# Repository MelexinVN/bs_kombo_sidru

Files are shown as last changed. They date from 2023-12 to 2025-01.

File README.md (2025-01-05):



# СИДРУ
## СветоИзлучающее Декоративное Радиоуправляемое Устройство

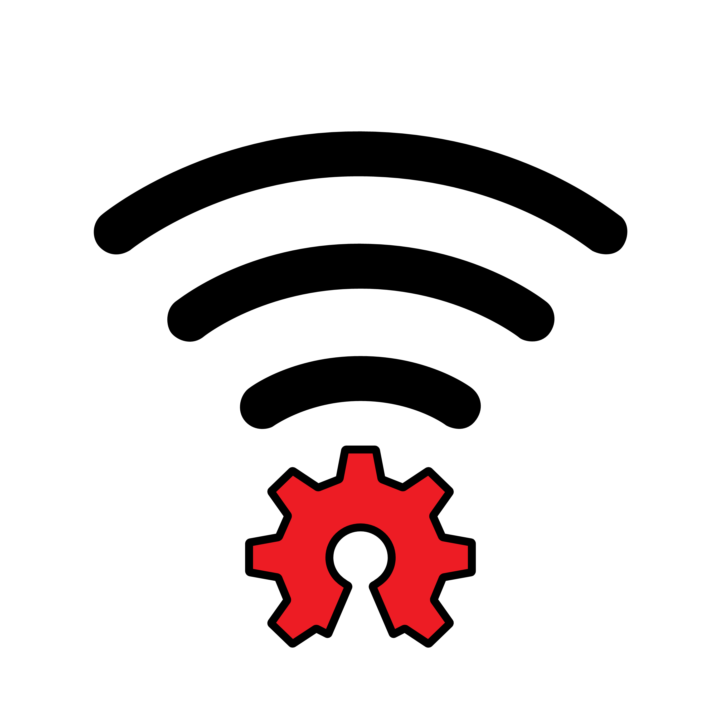
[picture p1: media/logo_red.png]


В рамках проекта ["КомБО"](https://github.com/MelexinVN/bs_kombo) разработано декоративное устройство на адресных светодиодах, управляемое по радиоканалу.

Устройство состоит из двух частей - декоративная часть и пульт управления.

Обе части содержат схему управления на микроконтроллере stm32f030f4p6, радиомодуль nrf24l01+, и схему питания.
В декоративной части микроконтроллер управляет адресными светодиодами ws2812. 
В данном случае светодиоды расположены на модуле в виде кольца (могут быть отдельными модулями, в виде светодиодной ленты и т.п.)

В пульте управления микроконтроллер в зависимости от состояния чувствительного элемента отправляет различные команды в ответ на запросы декоративного устройства.

Здесь в качестве чувствительных элементов используются датчики касания TTP223 (могут быть использованы кнопки, выходы реле, герконы и т.п.)

As part of the "КомБО" project, a decorative device based on addressable LEDs, controlled via a radio channel, has been developed.

The device consists of two parts - a decorative part and a control panel.

Both parts contain a control circuit on the stm32f030f4p6 microcontroller, an nrf24l01+ radio module, and a power supply circuit.
In the decorative part, the microcontroller controls the ws2812 addressable LEDs.
In this case, the LEDs are located on the module in the form of a ring (can be separate modules, in the form of an LED strip, etc.)

In the control panel, the microcontroller, depending on the state of the sensitive element, sends various commands in response to requests from the decorative device.

Here, TTP223 touch sensors are used as sensitive elements (buttons, relays, etc. can be used)

## Схема соединений пульта управления. Control panel connection diagram

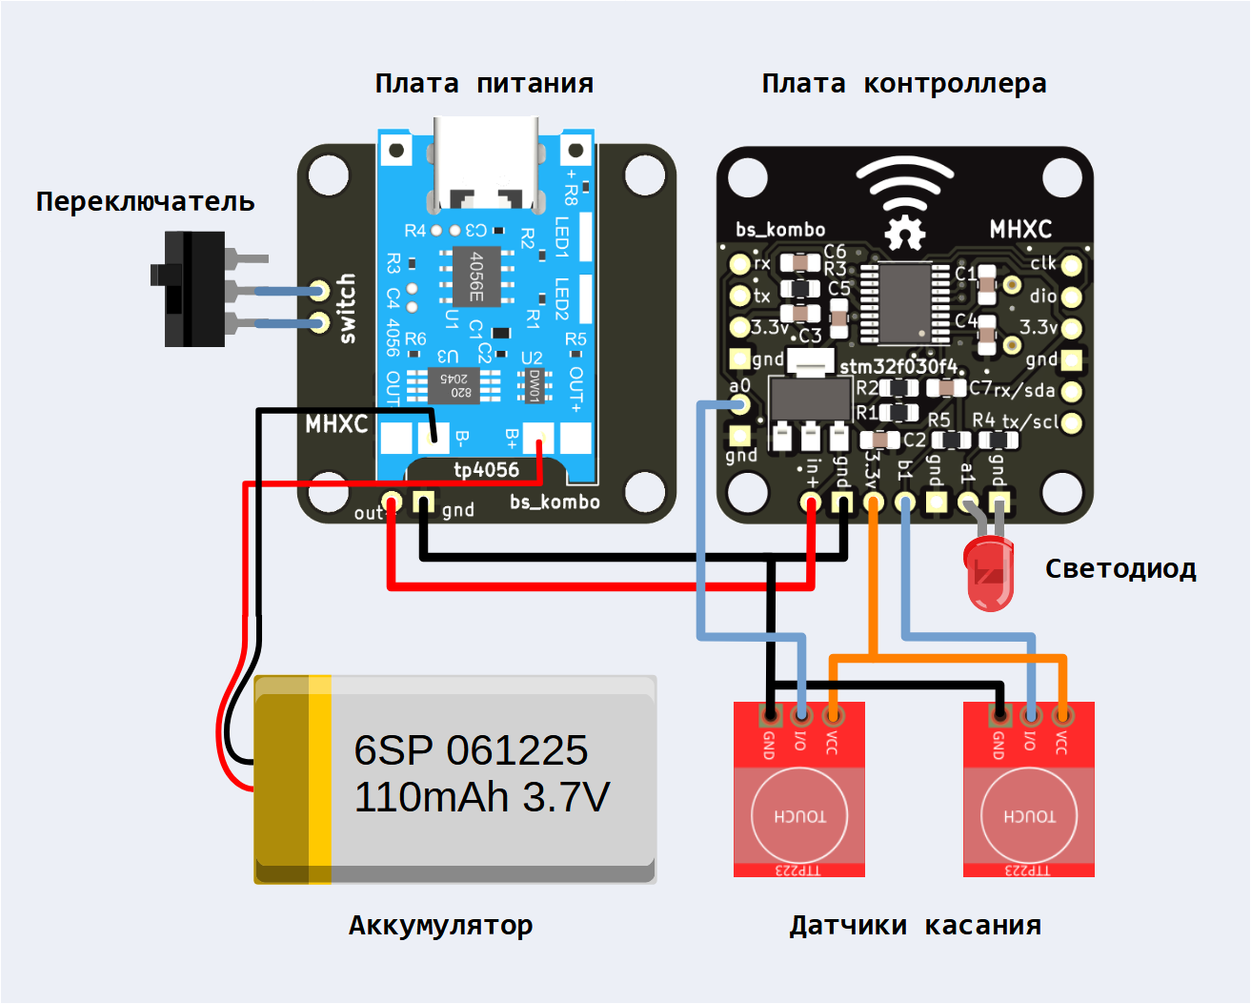
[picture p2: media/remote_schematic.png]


## Схема соединений декоративной части. Connection diagram of the decorative part

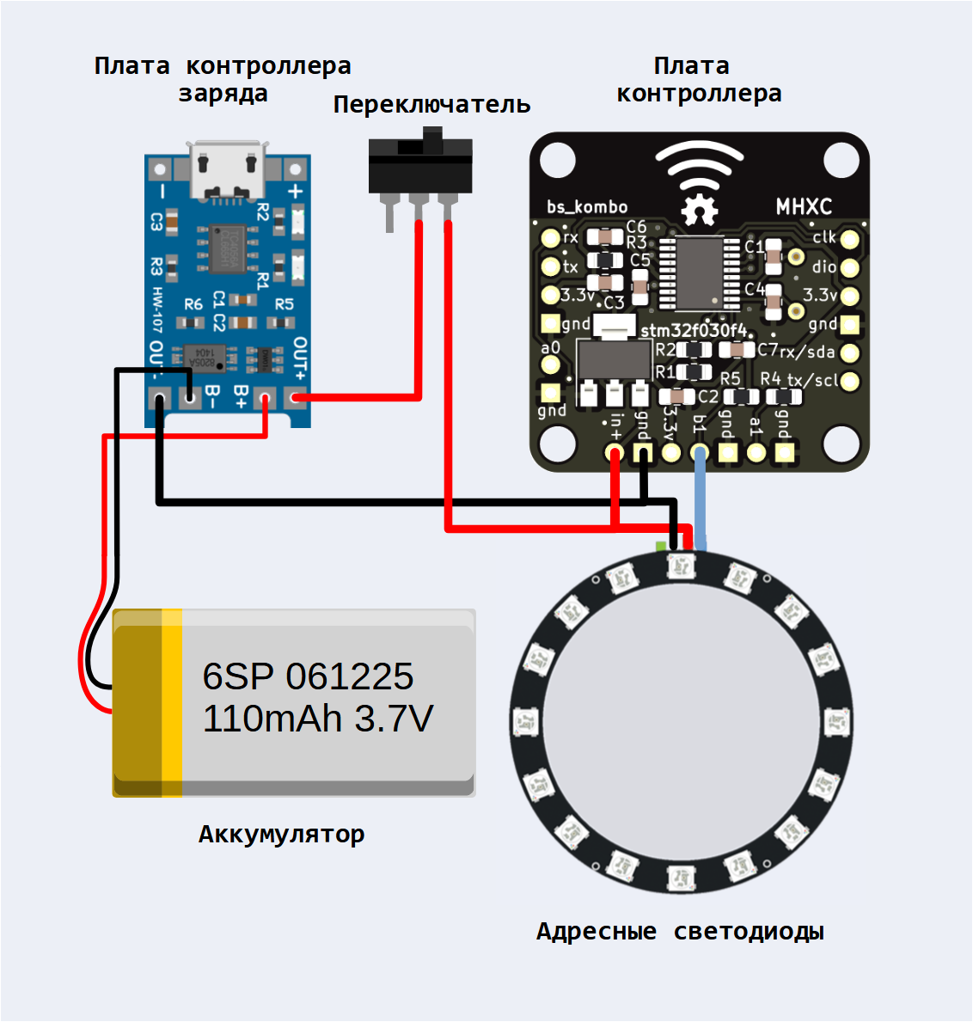
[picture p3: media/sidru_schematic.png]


## Пример готового устройства. Example of a finished device

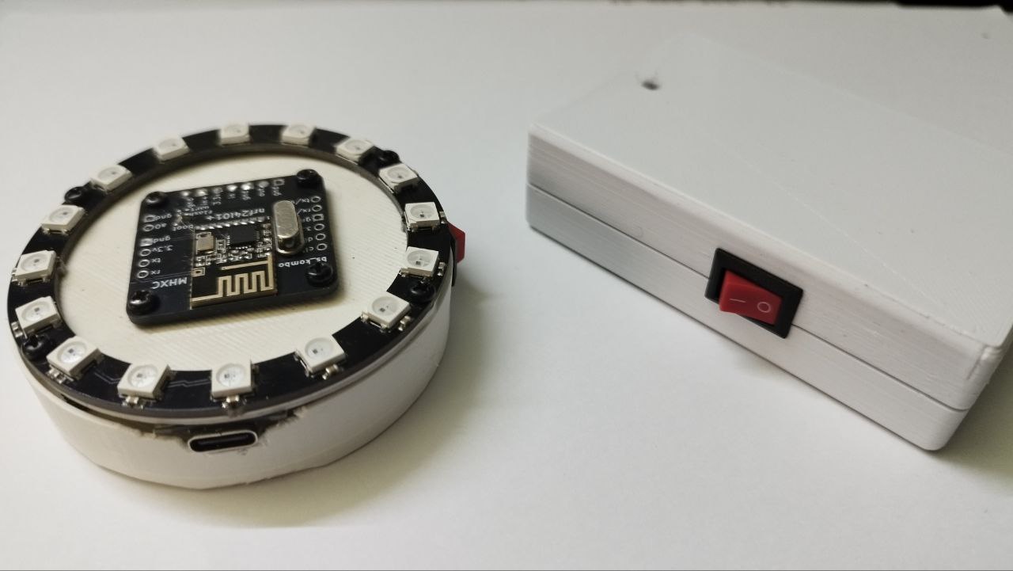
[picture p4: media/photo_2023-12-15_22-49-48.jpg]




### Планы по развитию:
- **Добавление новых световых эффектов**
- **Добавление исполнений для других микроконтроллеров и большего числа светодиодов**
- **Проекты исходников на других IDE, в частности STM32CubeIDE**
- **Пример исполнения для подсветки комнаты**

### Development plans:
- **Adding new lighting effects**
- **Add versions for other microcontrollers and more LEDs**
- **Source projects on other IDEs, in particular STM32CubeIDE**
- **Example of design for room lighting**

### Репозиторий содержит:
- ***Исполняемые файлы и исходники ПО декоративной части и пульта управления***. Программы разработаны в Keil µVision V5.38.0.0 (MDK-Lite).
- ***Гербер-файлы и исходники проектов используемых печатных плат***. Платы разработаны в KiCad 7.0.1, дополнительно в папках проекта можно найти архив 3д-моделей компонентов, а также интерактивный список компонентов (BOM).
- ***STL-файлы и исходники 3д-моделей используемых 3д-печатных деталей и корпусов***. Модели разработаны в OpenSCAD version 2021.01.

### The repository contains:
- ***Executable files and software sources for the decorative part and the control panel***. The programs were developed in Keil µVision V5.38.0.0 (MDK-Lite).
- ***Gerber files and source codes for designs of printed circuit boards used***. The boards were developed in KiCad 7.0.1; in addition, in the project folders you can find an archive of 3D models of components, as well as an interactive list of components (BOM).
- ***STL files and sources of 3D models of used 3D printed parts and cases***. The models were developed in OpenSCAD version 2021.01.

## Наши ресурсы:

### Основной репозиторий: [bs_kombo](https://github.com/MelexinVN/bs_kombo)

### Электронная почта: 		    [bskombo@yandex.ru](bskombo@yandex.ru)

### Социальные сети:

- паблик ВКонтакте: 			  [vk.com/bs_kombo](https://vk.com/bs_kombo)
- Telegram-канал: 	        [t.me/bskombo](https://t.me/bskombo)
- Telegram-чат: 	          [t.me/bs_kombo_chat](https://t.me/bs_kombo_chat)

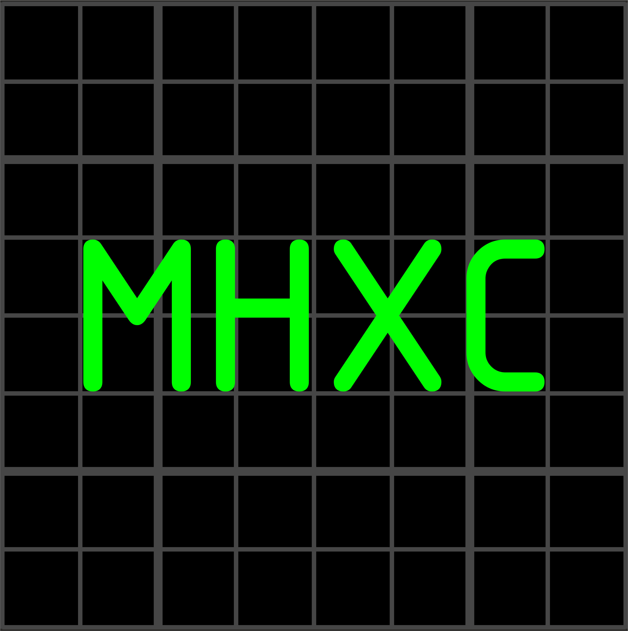
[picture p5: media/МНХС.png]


### Авторы всегда рады отзывам и любым конструктивным предложениям по улучшению проекта! 
### The authors are always happy to receive feedback and any constructive suggestions for improving the project!

## Лицензия
Проект распространяется под лицензией Creative Commons Attribution-ShareAlike 4.0 [CC BY-SA 4.0](https://creativecommons.org/licenses/by-sa/4.0/), 
а программное обеспечение - под лицензией GNU General Public License v3.0 [GPL-3.0 license](https://github.com/MelexinVN/bs_kombo/blob/main/LICENSE)

## License
This project is licensed under the Creative Commons 4.0 license with Attribution-ShareAlike [CC BY-SA 4.0](https://creativecommons.org/licenses/by-sa/4.0/), 
and the software is licensed under the GNU General Public License v3.0 [GPL-3.0 license](https://github.com/MelexinVN/bs_kombo/blob/main/LICENSE)

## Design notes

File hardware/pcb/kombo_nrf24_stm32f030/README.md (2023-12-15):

### Плата для МК stm32f030f4p6 в корпусе TSSOP-20 с модулем nrf24l01 в smd исполнении.

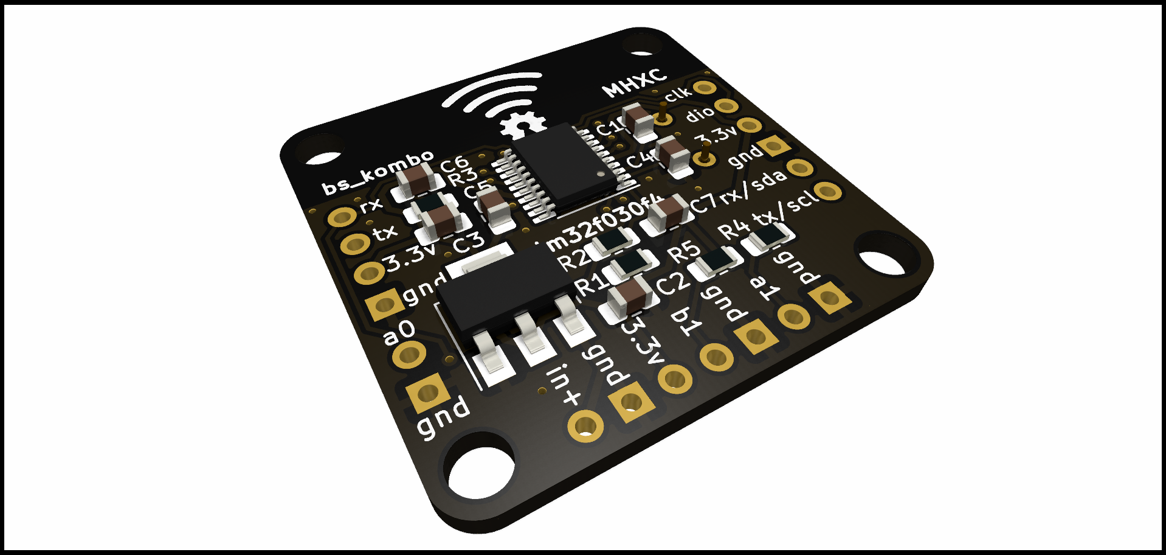
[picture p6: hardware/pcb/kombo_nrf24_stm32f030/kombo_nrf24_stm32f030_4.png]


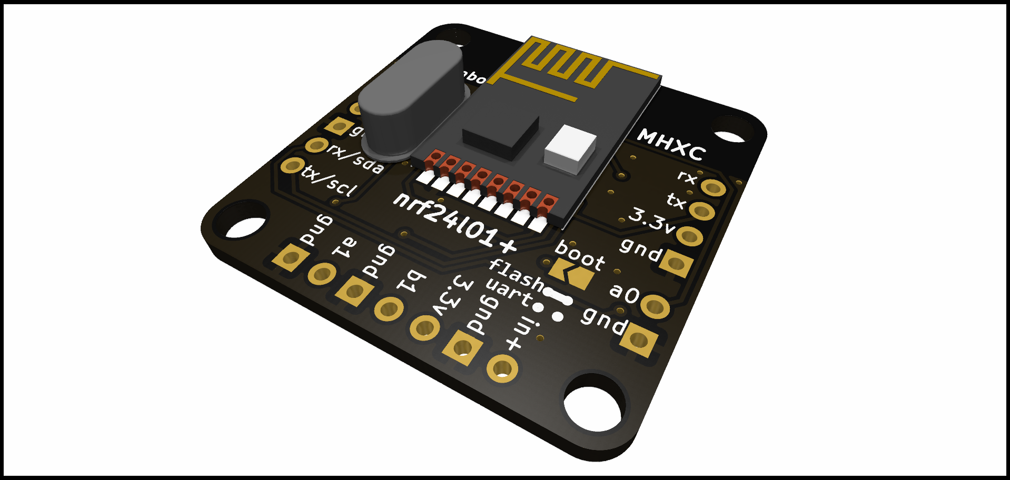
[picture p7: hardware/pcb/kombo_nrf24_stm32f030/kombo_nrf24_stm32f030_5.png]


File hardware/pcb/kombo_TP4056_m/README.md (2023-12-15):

### Плата питания с модулем контроллером заряда TP4056.
### Расположение выходов питания соответствует плате kombo_nrf24_stm32f030, плюсовой контакт разомкнут монтажными отверстиями под переключатель

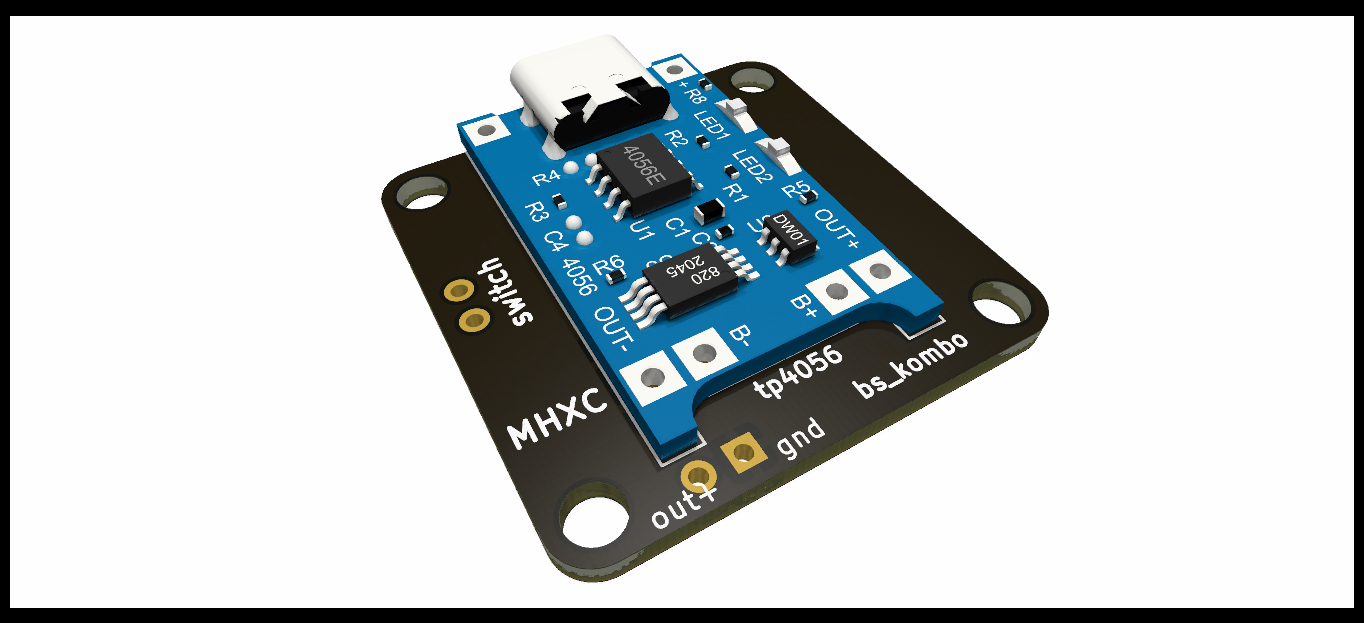
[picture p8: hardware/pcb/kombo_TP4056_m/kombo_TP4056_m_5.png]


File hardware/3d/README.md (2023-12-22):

## 3Д модели и исходники 3д-печатных деталей устройства.
### 3Д модели созданы в программе [OpenSCAD](https://openscad.org/)
### Корпус пульта управления создан с использованием библиотеки YAPP_Box 
### [Yet Another Parameterised Projectbox generator](https://mrwheel-docs.gitbook.io/yappgenerator_en/)
**!!! При печати корпуса пульта без поддержек рекомендуется включить настройку "Сделать нависания печатаемыми"!!!**

## Крышка

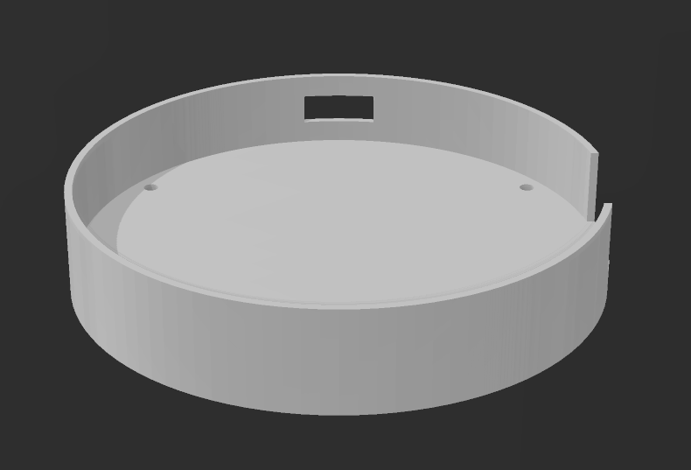
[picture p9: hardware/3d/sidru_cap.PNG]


### Основание

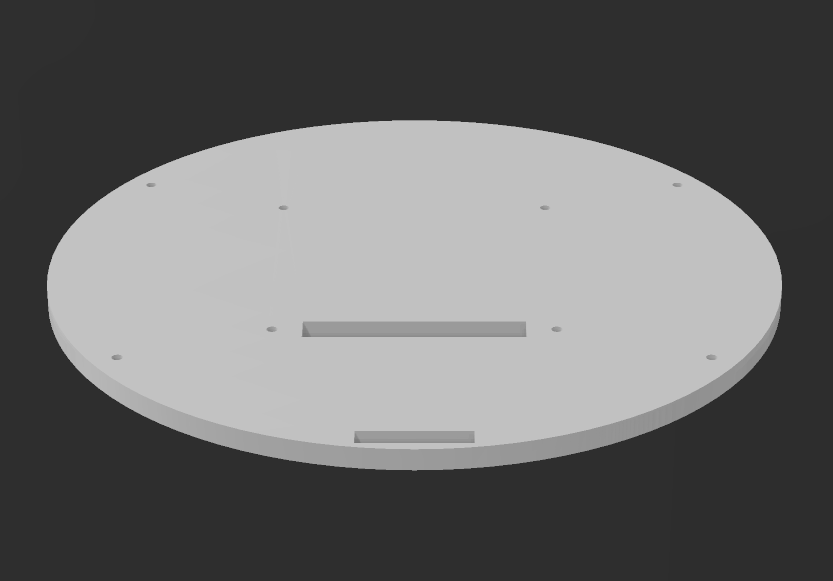
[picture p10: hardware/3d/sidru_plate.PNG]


### Пульт управления

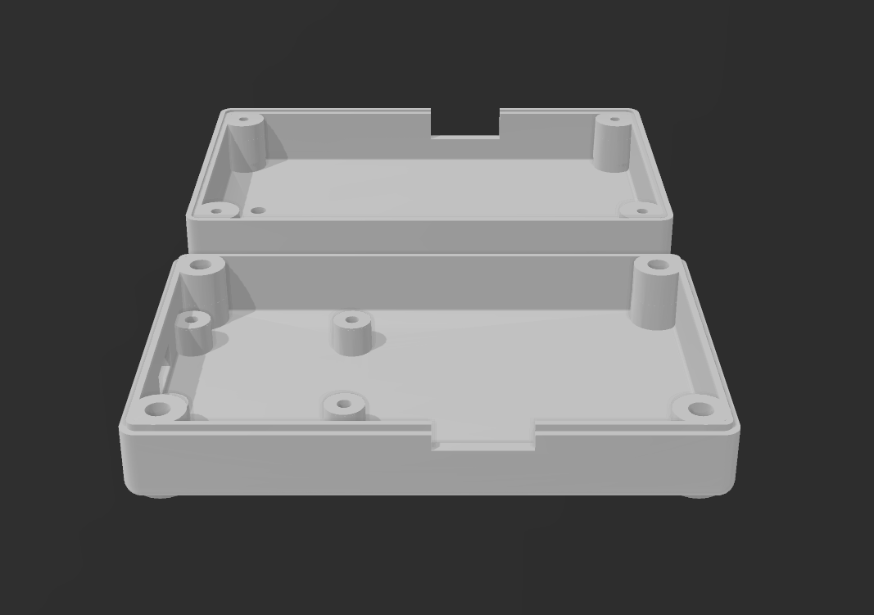
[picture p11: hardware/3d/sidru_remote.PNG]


### Стойка для печатных плат

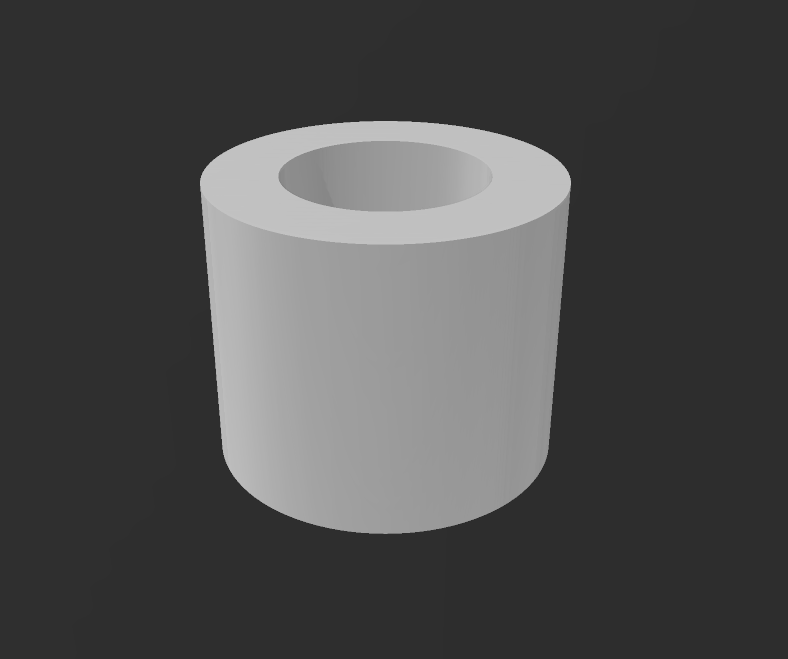
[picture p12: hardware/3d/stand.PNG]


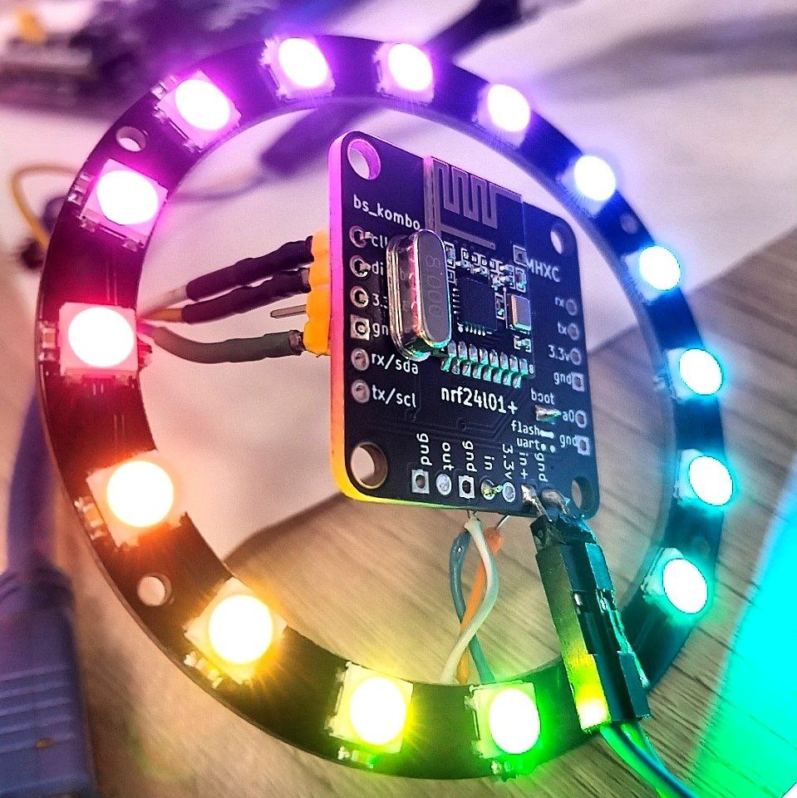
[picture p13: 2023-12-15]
media/photo.jpg

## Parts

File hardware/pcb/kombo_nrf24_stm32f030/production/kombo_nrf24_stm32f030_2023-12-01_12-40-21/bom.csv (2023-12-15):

Designator | Footprint | Quantity | Value | LCSC Part #
C1, C4 | 0805 | 2 | 22p
C2, C5, C6 | 0805 | 3 | 100n
C3, C7 | 0805 | 2 | 10u
J1 | PinHeader_1x07_P2.54mm_Vertical | 1 | Conn_01x07
J2 | PinHeader_1x04_P2.54mm_Vertical | 1 | Conn_01x04
J3 | PinHeader_1x06_P2.54mm_Vertical | 1 | Conn_01x06
J4 | PinHeader_1x02_P2.54mm_Vertical | 1 | Conn_01x02
JP1 | SolderJumper-2_P1.3mm_Open_TrianglePad1.0x1.5mm | 1 | SolderJumper_2_Open
R1, R3, R5 | 0805 | 3 | 10k
R2, R4 | 0805 | 2 | 620
U1 | NRF24L01-Module-SMD | 1 | NRF24L01_Breakout
U2 | SOT-223-3_TabPin2 | 1 | AMS1117-3.3
U3 | TSSOP-20_4.4x6.5mm_P0.65mm | 1 | STM32F030F4Px
Y1 | Crystal_HC49-U_Vertical | 1 | Crystal

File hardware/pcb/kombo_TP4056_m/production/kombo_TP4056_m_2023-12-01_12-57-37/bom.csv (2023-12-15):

Designator | Footprint | Quantity | Value | LCSC Part #
DS1 | TP4056-18650 | 1 | TP4056 module
J1, J2 | PinHeader_1x02_P2.54mm_Vertical | 2 | Conn_01x02

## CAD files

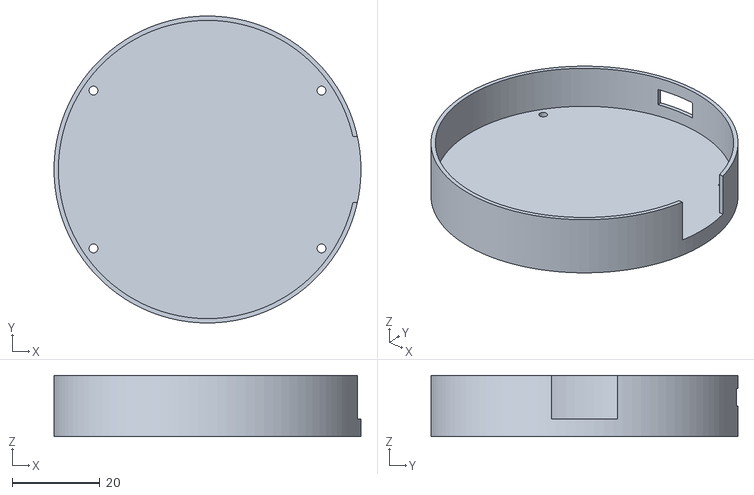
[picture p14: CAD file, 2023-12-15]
hardware/3d/sidru_cap.stl
70.0 x 70.0 x 14.0

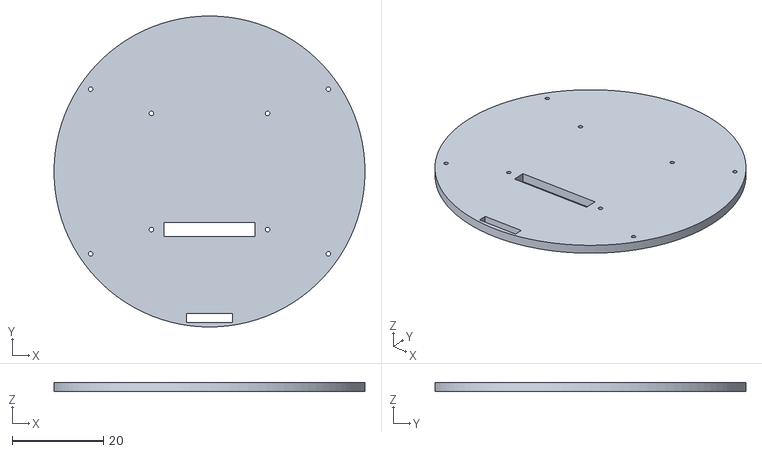
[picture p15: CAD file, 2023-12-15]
hardware/3d/sidru_plate.stl
68.0 x 68.0 x 2.00

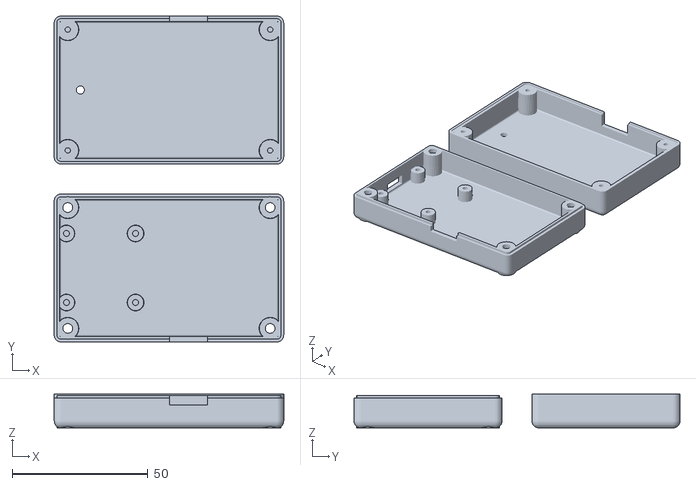
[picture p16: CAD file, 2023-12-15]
hardware/3d/sidru_remote.stl
84.5 x 120.0 x 12.5

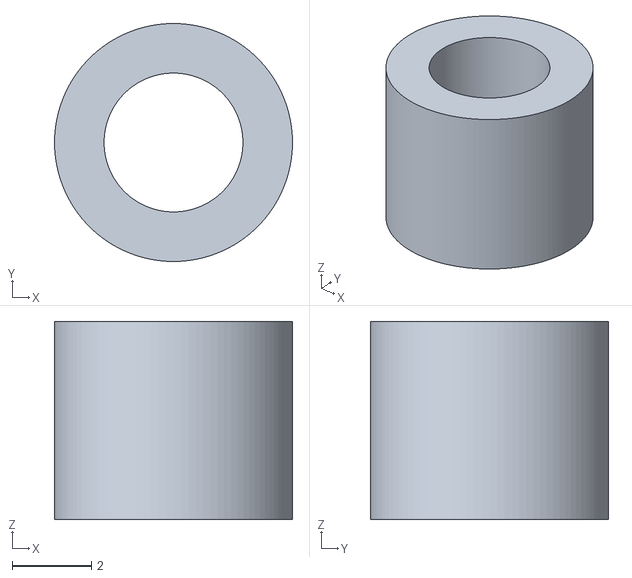
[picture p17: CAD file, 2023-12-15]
hardware/3d/stand.stl
6.00 x 6.00 x 5.00

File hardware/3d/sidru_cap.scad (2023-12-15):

/***************************************************************
sidru_plate.scad
Программа генерации 3д модели основания для компактного варианта
СветоИзлучающего Декоративного Радиоуправляемого Устройства
(СИДРУ) проекта КомБО (Открытые системы беспроводной коммуникации)

Автор: MelexinVN (Мелехин В.Н.)
***************************************************************/

$fn = 100;          //количество полигонов

edge_height = 10;   //высота стенки
thickness = 4;      //толщина основания
ext_diameter = 68;  //диаметр основания
int_diameter = 2;   //диаметр внутренних отверстий

difference()    //Вычитаем из основания объединение тел, формирующих отверстия
{
    union()     //объединяем дно и стенку, формируем основание
    {
        translate([0,0,edge_height/2])  
        {  
            difference()    //разность цилиндров, формирующих стенку
            {
                cylinder(h = edge_height+thickness, d = ext_diameter+2, center = true); 
                cylinder(h = edge_height+thickness+1, d = ext_diameter, center = true); 
            }
        }
        //цилиндр, формирующий дно
        cylinder(h = thickness, d = ext_diameter, center = true); 
    }
    union()     //объединяем тела, формирующие отверстия
    {
     //Ряд смещенных на определенное расстояние цилиндров, задающих отверстия для крепежа
        translate([26,18,0])
            cylinder(h = thickness+1, d = int_diameter, center = true);
        translate([26,-18,0])
            cylinder(h = thickness+1, d = int_diameter, center = true);
        translate([-26,18,0])
            cylinder(h = thickness+1, d = int_diameter, center = true);
        translate([-26,-18,0])
            cylinder(h = thickness+1, d = int_diameter, center = true);
      //Параллелепипеды, формирующие прямоугольные вырезы
        translate([ext_diameter/2,0,(edge_height+thickness)/2])
            //вырез под выключатель
            cube([15,15,edge_height],center = true);
        translate([0,ext_diameter/2,(edge_height+thickness)/2])
            //вырез под usb-разъем контроллера заряда
            cube([10,10,4],center = true);
    }
}

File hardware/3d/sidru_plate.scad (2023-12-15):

/***************************************************************
sidru_plate.scad
Программа генерации 3д модели основания для компактного варианта
СветоИзлучающего Декоративного Радиоуправляемого Устройства
(СИДРУ) проекта КомБО (Открытые системы беспроводной коммуникации)

Автор: MelexinVN (Мелехин В.Н.)
***************************************************************/

$fn = 100;          //количество полигонов

height = 2;         //толщина основания
ext_diameter = 68;  //диаметр основания
int_diameter = 1;   //диаметр внутренних отверстий

difference()    //разность
{
    cylinder(h = height, d = ext_diameter, center = true); 
    //из цилиндра с заданными параметрами
    //вычитаем объединение фигур
    union()
    {
    //Два смещенный на определенное расстоение параллелипипида, задающие вырезы для вывода проводов (для генерации задней крышки без этих вырезов закомментировать их)
        translate([0,-ext_diameter/2 + 2,0])
            cube([10,2,height+1], center = true);
        translate([0,-12.7,0])
            cube([20,3,height+1], center = true);
     //Ряд смещенных на определенное расстояние цилиндров, задающих отверстия для крепежа печатных плат
        translate([12.7,12.7,0])
            cylinder(h = height+1, d = int_diameter, center = true);
        translate([12.7,-12.7,0])
            cylinder(h = height+1, d = int_diameter, center = true);
        translate([-12.7,12.7,0])
            cylinder(h = height+1, d = int_diameter, center = true);
        translate([-12.7,-12.7,0])
            cylinder(h = height+1, d = int_diameter, center = true);
        translate([26,18,0])
            cylinder(h = height+1, d = int_diameter, center = true);
        translate([26,-18,0])
            cylinder(h = height+1, d = int_diameter, center = true);
        translate([-26,18,0])
            cylinder(h = height+1, d = int_diameter, center = true);
        translate([-26,-18,0])
            cylinder(h = height+1, d = int_diameter, center = true);
    }
}

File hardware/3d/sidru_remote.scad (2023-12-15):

/***************************************************************
sidru_remote.scad
Программа генерации 3д модели корпуса пульта управления
СветоИзлучающего Декоративного Радиоуправляемого Устройства
(СИДРУ) проекта КомБО (Открытые системы беспроводной коммуникации)

Используется библиотека YAPP_Box 
Yet Another Parameterised Projectbox generator
https://mrwheel-docs.gitbook.io/yappgenerator_en/

Автор: MelexinVN (Мелехин В.Н.)
***************************************************************/

//---------------------------------------------------------
// This design is parameterized based on the size of a PCB.
//---------------------------------------------------------
include <library/YAPPgenerator_v16.scad>

// Note: length/lengte refers to X axis, 
//       width/breedte to Y, 
//       height/hoogte to Z

/*
      padding-back|<------pcb length --->|<padding-front
                            RIGHT
        0    X-as ---> 
        +----------------------------------------+   ---
        |                                        |    ^
        |                                        |   padding-right 
        |                                        |    v
        |    -5,y +----------------------+       |   ---              
 B    Y |         | 0,y              x,y |       |     ^              F
 A    - |         |                      |       |     |              R
 C    a |         |                      |       |     | pcb width    O
 K    s |         |                      |       |     |              N
        |         | 0,0              x,0 |       |     v              T
      ^ |   -5,0  +----------------------+       |   ---
      | |                                        |    padding-left
      0 +----------------------------------------+   ---
        0    X-as --->
                          LEFT
*/

//-- which half do you want to print?
printLidShell       = true;
printBaseShell      = true;

//-- Edit these parameters for your own board dimensions
wallThickness       = 2;
basePlaneThickness  = 2;
lidPlaneThickness   = 2;

//-- Total height of box = basePlaneThickness + lidPlaneThickness 
//--                     + baseWallHeight + lidWallHeight
//-- space between pcb and lidPlane :=
//--      (baseWallHeight+lidWallHeight) - (standoffHeight+pcbThickness)
baseWallHeight      = 10;
lidWallHeight       = 10;

//-- ridge where base and lid off box can overlap
//-- Make sure this isn't less than lidWallHeight
ridgeHeight         = 1;
ridgeSlack          = 0.1;
roundRadius         = 2.54;

//-- pcb dimensions
pcbLength           = 30.5;
pcbWidth            = 30.5;
pcbThickness        = 1.5;

//-- How much the PCB needs to be raised from the base
//-- to leave room for solderings and whatnot
standoffHeight      = 5;
pinDiameter         = 1.0;
pinHoleSlack        = 1.0;
standoffDiameter    = 6.0;
standoffSupportHeight   = 5;
standoffSupportDiameter = 0.1;
                            
//-- padding between pcb and inside wall
paddingFront        = 50;
paddingBack         = 0;
paddingRight        = 10;
paddingLeft         = 10;


//-- D E B U G ----------------------------
showSideBySide      = true;       //-> true
onLidGap            = 0;
shiftLid            = 1;
hideLidWalls        = false;       //-> false
colorLid            = "yellow";   
hideBaseWalls       = false;       //-> false
colorBase           = "white";
showPCB             = false;      //-> false
showMarkers         = false;      //-> false
inspectX            = 0;  //-> 0=none (>0 from front, <0 from back)
inspectY            = 0;
//-- D E B U G ----------------------------


//-- pcb_standoffs  -- origin is pcb[0,0,0]
// (0) = posx
// (1) = posy
// (2) = { yappBoth | yappLidOnly | yappBaseOnly }
// (3) = { yappHole, YappPin }
pcbStands = [
                 [2.54,2.54,yappBaseOnly,yappHole]
                ,[30.5-2.54,2.54,yappBaseOnly,yappHole]
                ,[30.5 - 2.54,30.5-2.54,yappBaseOnly,yappHole]
                ,[2.5,30.5-2.54,yappBaseOnly,yappHole]
             ];

//-- Lid plane    -- origin is pcb[0,0,0]
// (0) = posx
// (1) = posy
// (2) = width
// (3) = length
// (4) = angle
// (5) = { yappRectangle | yappCircle }
// (6) = { yappCenter }
cutoutsLid =  [ 
                //Отверстие под светодиод
                //[pcbWidth/4, pcbLength/2, 3, 3, 0, yappCircle,yappCenter]
              ];

//-- base plane    -- origin is pcb[0,0,0]
// (0) = posx
// (1) = posy
// (2) = width
// (3) = length
// (4) = angle
// (5) = { yappRectangle | yappCircle }
// (6) = { yappCenter }
cutoutsBase = [

              ];

//-- front plane  -- origin is pcb[0,0,0]
// (0) = posy
// (1) = posz
// (2) = width
// (3) = height
// (4) = angle
// (5) = { yappRectangle | yappCircle }
// (6) = { yappCenter }
cutoutsFront =  [

                ];

//-- back plane  -- origin is pcb[0,0,0]
// (0) = posy
// (1) = posz
// (2) = width
// (3) = height
// (4) = angle
// (5) = { yappRectangle | yappCircle }
// (6) = { yappCenter }
cutoutsBack = [
                //Отверстие под USB разъем контроллера заряда
                [pcbWidth/2, -standoffHeight, 10, 4, 0, yappRectangle,yappCenter]
              ];

//-- left plane   -- origin is pcb[0,0,0]
// (0) = posx
// (1) = posz
// (2) = width
// (3) = height
// (4) = angle
// (5) = { yappRectangle | yappCircle }
// (6) = { yappCenter }
cutoutsLeft = [
                //Отверстие под выключатель
                [pcbLength+10, 0, 14, 9, 0, yappRectangle]
              ];

//-- right plane   -- origin is pcb[0,0,0]
// (0) = posx
// (1) = posz
// (2) = width
// (3) = height
// (4) = angle
// (5) = { yappRectangle | yappCircle }
// (6) = { yappCenter }
cutoutsRight = [

               ];

//-- connectors -- origen = box[0,0,0]
// (0) = posx
// (1) = posy
// (2) = screwDiameter
// (3) = insertDiameter
// (4) = outsideDiameter
// (5) = { yappAllCorners }
connectors   = [
                    [5,5, 3, 2, 8, yappAllCorners]
               ];


//-- base mounts -- origen = box[x0,y0]
// (0) = posx | posy
// (1) = screwDiameter
// (2) = width
// (3) = height
// (4..7) = yappLeft / yappRight / yappFront / yappBack (one or more)
// (5) = { yappCenter }
baseMounts   = [

               ];

               
//-- snapJons -- origen = shell[x0,y0]
// (0) = posx | posy
// (1) = width
// (2..5) = yappLeft / yappRight / yappFront / yappBack (one or more)
// (n) = { yappSymmetric }
snapJoins   =   [

                ];

 
//-- origin of labels is box [0,0,0]
// (0) = posx
// (1) = posy/z
// (2) = orientation
// (3) = depth
// (4) = plane {lid | base | left | right | front | back }
// (5) = font
// (6) = size
// (7) = "label text"
labelsPlane =  [

                ];

module lidHook()
{
  %translate([-20, -20, 0]) cube(5);
}

//--- this is where the magic hapens ---
YAPPgenerate();

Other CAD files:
hardware/3d/stand.scad

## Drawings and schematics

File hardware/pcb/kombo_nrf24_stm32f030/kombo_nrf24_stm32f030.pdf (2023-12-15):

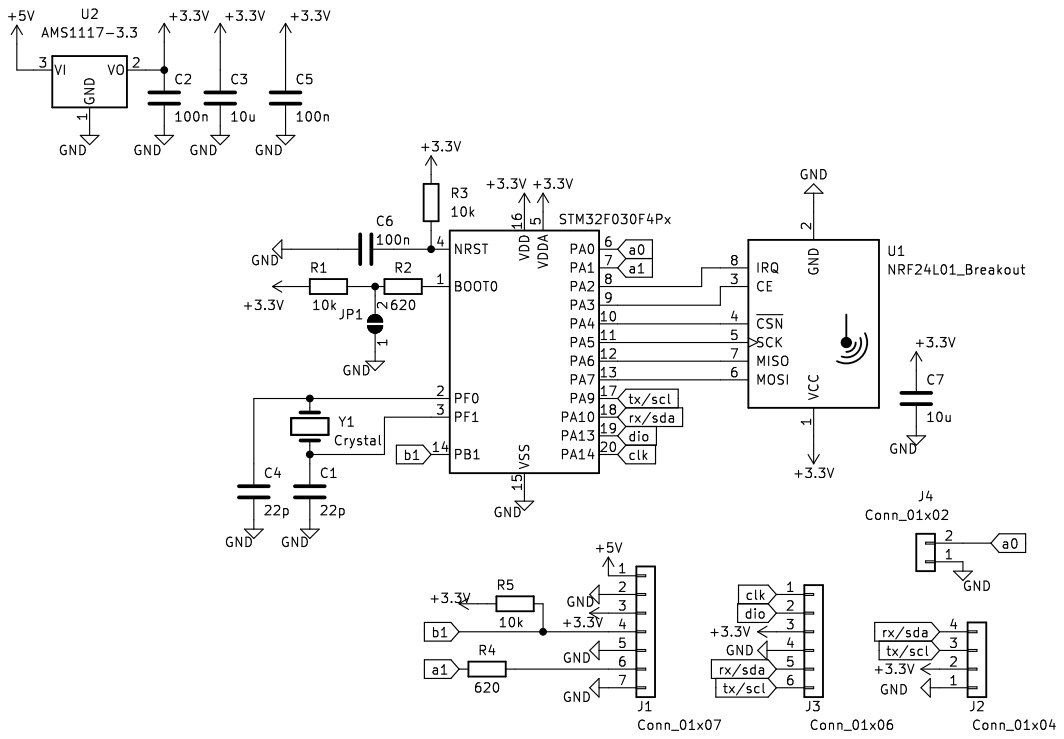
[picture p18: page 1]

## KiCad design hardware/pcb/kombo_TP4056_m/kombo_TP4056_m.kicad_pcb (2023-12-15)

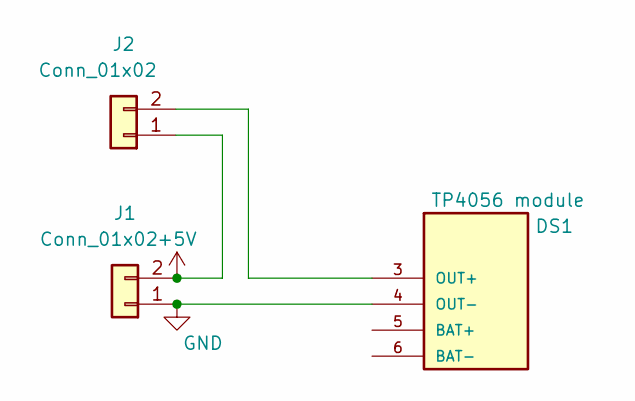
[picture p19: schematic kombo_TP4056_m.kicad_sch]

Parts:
DS1: TP4056 module; TP4056-18650; PARTREV N/A
J1, J2: Conn_01x02; PinHeader_1x02_P2.54mm_Vertical

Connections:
+5V: J1.2, J2.1
GND: DS1.4 (OUT-), J1.1
unnamed: DS1.3 (OUT+), J2.2

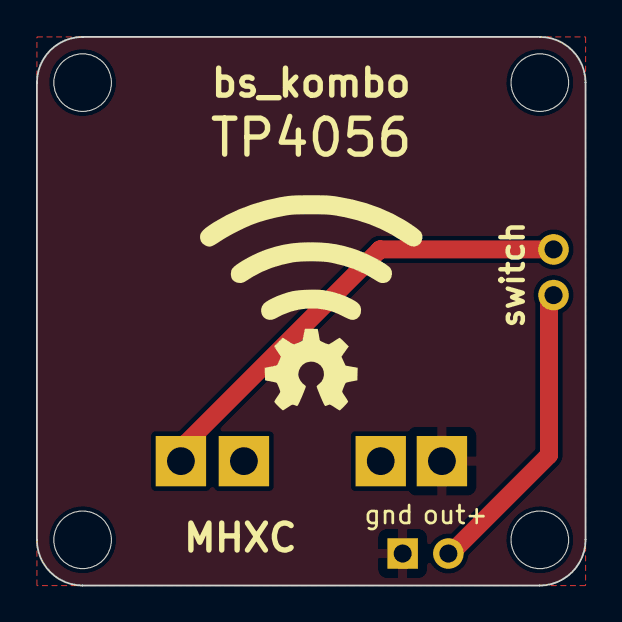
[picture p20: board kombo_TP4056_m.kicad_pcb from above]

Board: 2 copper layers, 30.5 x 30.5 mm, 3 parts (1 on the bottom side), 3 nets.

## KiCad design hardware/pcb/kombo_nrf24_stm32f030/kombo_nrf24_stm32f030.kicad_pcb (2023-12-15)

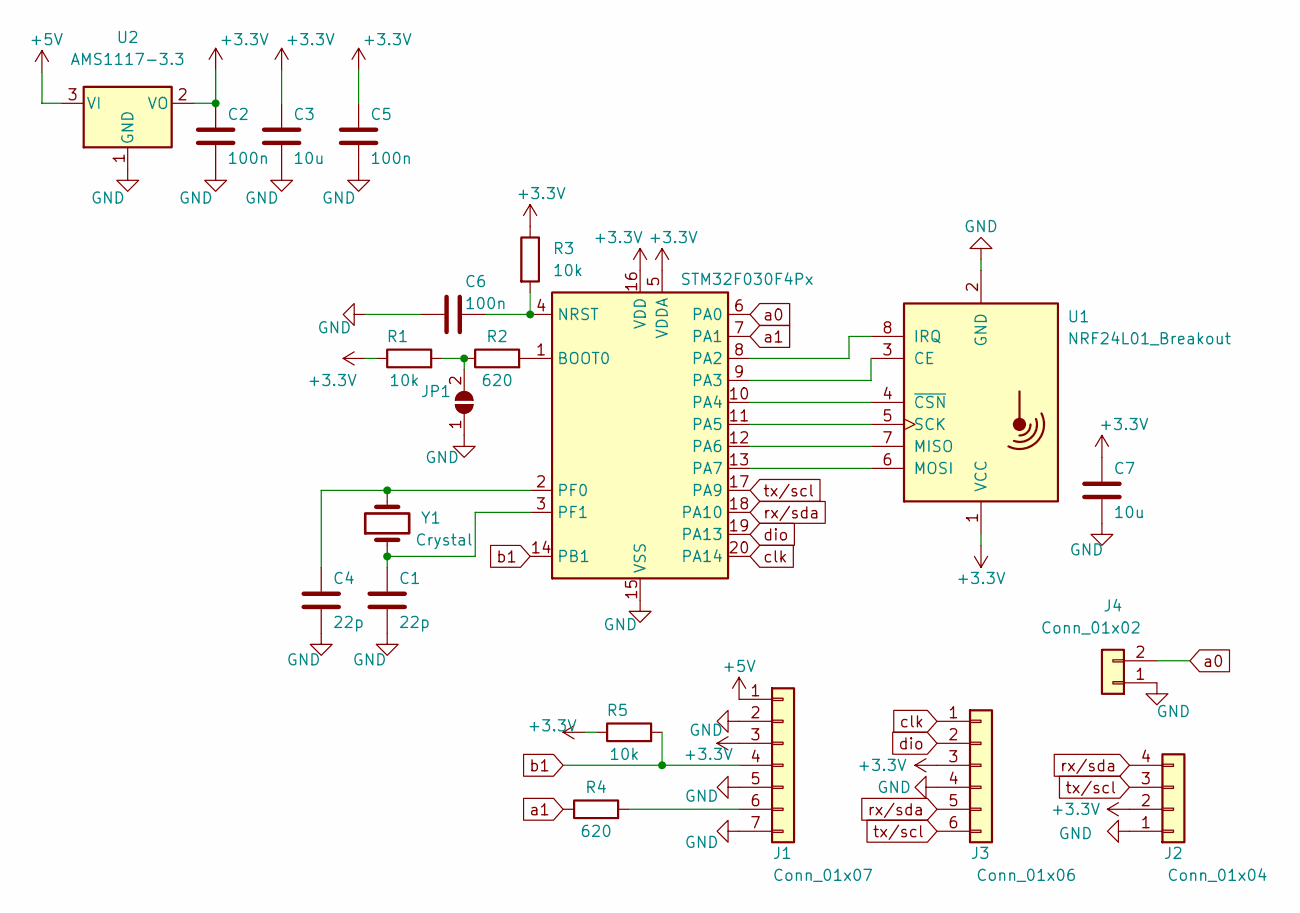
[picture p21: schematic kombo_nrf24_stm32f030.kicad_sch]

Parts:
C1, C4: 22p; C_0805_2012Metric_Pad1.18x1.45mm_HandSolder
C2, C5, C6: 100n; C_0805_2012Metric_Pad1.18x1.45mm_HandSolder
C3, C7: 10u; C_0805_2012Metric_Pad1.18x1.45mm_HandSolder
J1: Conn_01x07; PinHeader_1x07_P2.54mm_Vertical
J2: Conn_01x04; PinHeader_1x04_P2.54mm_Vertical
J3: Conn_01x06; PinHeader_1x06_P2.54mm_Vertical
J4: Conn_01x02; PinHeader_1x02_P2.54mm_Vertical
JP1: SolderJumper_2_Open; SolderJumper-2_P1.3mm_Open_TrianglePad1.0x1.5mm
R1, R3, R5: 10k; R_0805_2012Metric_Pad1.20x1.40mm_HandSolder
R2, R4: 620; R_0805_2012Metric_Pad1.20x1.40mm_HandSolder
U1: NRF24L01_Breakout; NRF24L01-Module-SMD
U2: AMS1117-3.3; SOT-223-3_TabPin2
U3: STM32F030F4Px; TSSOP-20_4.4x6.5mm_P0.65mm
Y1: Crystal; Crystal_HC49-U_Vertical

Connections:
+3V3: C2.1, C3.1, C5.1, C7.1, J1.3, J2.2, J3.3, R1.1, R3.1, R5.1, U1.1 (VCC), U2.2 (VO), U3.5 (VDDA), U3.16 (VDD)
+5V: J1.1, U2.3 (VI)
GND: C1.2, C2.2, C3.2, C4.2, C5.2, C6.2, C7.2, J1.2, J1.5, J1.7, J2.1, J3.4, J4.1, JP1.1 (A), U1.2 (GND), U2.1 (GND), U3.15 (VSS)
unnamed: J1.6, R4.2
unnamed: JP1.2 (B), R1.2, R2.1
unnamed: U1.3 (CE), U3.9 (PA3)
unnamed: U1.8 (IRQ), U3.8 (PA2)
unnamed: U1.7 (MISO), U3.12 (PA6)
unnamed: U1.6 (MOSI), U3.13 (PA7)
unnamed: U1.5 (SCK), U3.11 (PA5)
unnamed: U1.4 (~CSN), U3.10 (PA4)
unnamed: R2.2, U3.1 (BOOT0)
unnamed: C6.1, R3.2, U3.4 (NRST)
unnamed: C4.1, U3.2 (PF0), Y1.2
unnamed: C1.1, U3.3 (PF1), Y1.1
a0: J4.2, U3.6 (PA0)
but: J1.4, R5.2, U3.14 (PB1)
clk: J3.1, U3.20 (PA14)
dio: J3.2, U3.19 (PA13)
led: R4.1, U3.7 (PA1)
rx/sda: J2.4, J3.5, U3.18 (PA10)
tx/scl: J2.3, J3.6, U3.17 (PA9)

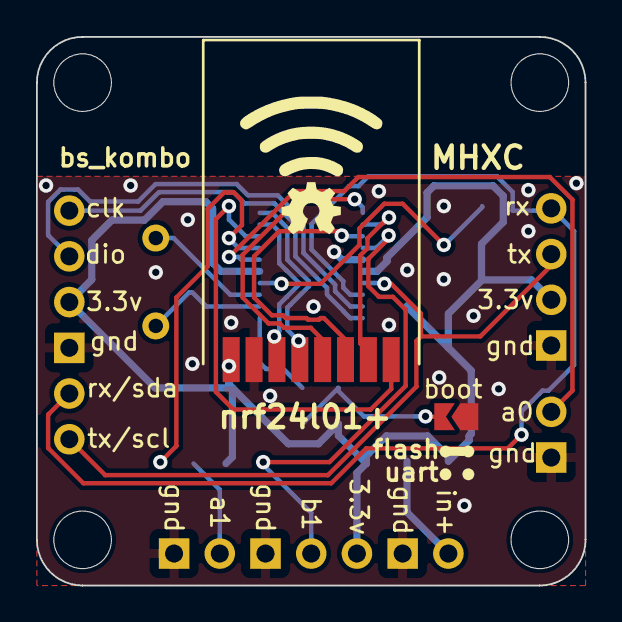
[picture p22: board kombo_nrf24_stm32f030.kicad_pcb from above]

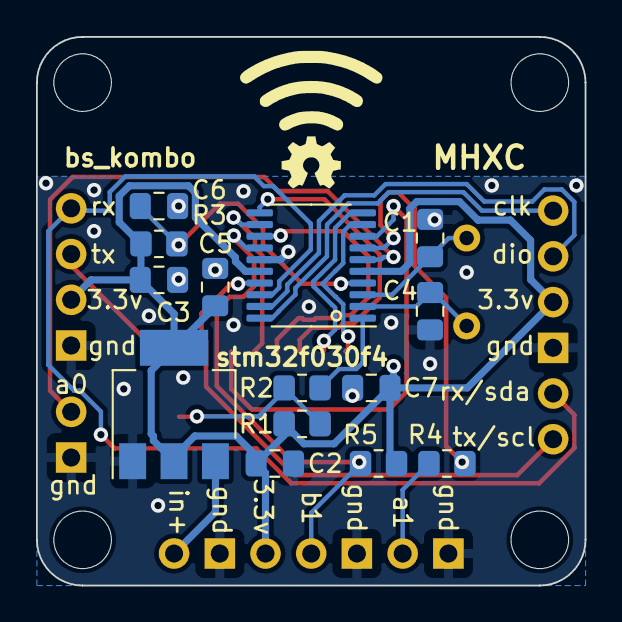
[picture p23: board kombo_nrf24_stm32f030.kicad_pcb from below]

Board: 2 copper layers, 30.5 x 30.5 mm, 21 parts (14 on the bottom side), 22 nets.

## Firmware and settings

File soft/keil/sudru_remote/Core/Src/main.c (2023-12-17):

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
/* Includes ------------------------------------------------------------------*/
#include "main.h"


/* USER CODE BEGIN PV */
//объявляем переменные
uint8_t f_but_1 = 0;			//флаг нажатия первой кнопки
uint8_t f_but_2 = 0;			//флаг нажатия второй кнопки

//внешние переменные и массивы
extern volatile uint8_t f_rx, f_tx;			//флаги приема и передачи
extern uint8_t tx_buf[TX_PLOAD_WIDTH];	//буфер передачи
extern uint8_t rx_buf[TX_PLOAD_WIDTH];	//буфер приема
/* USER CODE END PV */

void SystemClock_Config(void);
static void MX_GPIO_Init(void);
static void MX_IWDG_Init(void);
static void MX_SPI1_Init(void);
/* USER CODE BEGIN 0 */
//Процедура обработки прерывания при нажатии кнопки 1
void but_1_callback(void)
{
	f_but_1 = 1;			//поднимаем флаг
}
//Процедура обработки прерывания при нажатии кнопки 2
void but_2_callback(void)
{
	f_but_2 = 1;			//поднимаем флаг
}

//Процедура моргания светодиодом
void blink_led(uint8_t blink_counter)
{
	while (blink_counter)		//пока счетчик не равен 0
	{
		LED_ON();							//включаем светодиод
		LL_mDelay(10);				//ждем
		LED_OFF();						//выключаем светодиод
		if (blink_counter > 1) LL_mDelay(50);				//если не последнее моргание, ждем
		blink_counter--;			//декрементируем счетчик
	}
}

//Процедура приема радиомодуля
void nrf24l01_receive(void)
{
	if(f_rx)	//если флаг приема поднят (флаг поднимается по внешнему прерыванию от радиомодуля)
	{
		if (rx_buf[0] == OUR_ADDR)//если первый принятый байт совпадает с адресом устройства
		{
			if (f_but_1)						//если флаг нажатия кнопки 1 поднят
			{
				tx_buf[0] = SID_ADDR;	//записываем адрес 
				tx_buf[1] = ON_OFF;		//записываем команду включения/выключения
				nrf24_send(tx_buf);		//отправляем посылку в эфир
				f_but_1 = 0;					//опускам флаг
			}
			
			else if (f_but_2)				//если флаг нажатия кнопки 2 поднят
			{
				tx_buf[0] = SID_ADDR;	//записываем адрес 
				tx_buf[1] = MODE_UP;	//записываем команду изменения режима
				nrf24_send(tx_buf);		//отправляем посылку в эфир
				f_but_2 = 0;					//опускам флаг
			}
		}
		
		blink_led(1);							//моргаем светодиодом
		f_rx = 0;									//опускаем флаг приема
	}
}
/* USER CODE END 0 */

/**
  * @brief  The application entry point.
  * @retval int
  */
int main(void)
{
  /* MCU Configuration--------------------------------------------------------*/

  /* Reset of all peripherals, Initializes the Flash interface and the Systick. */

  LL_APB1_GRP2_EnableClock(LL_APB1_GRP2_PERIPH_SYSCFG);
  LL_APB1_GRP1_EnableClock(LL_APB1_GRP1_PERIPH_PWR);

  /* System interrupt init*/
  /* SysTick_IRQn interrupt configuration */
  NVIC_SetPriority(SysTick_IRQn, 3);

  /* Configure the system clock */
  SystemClock_Config();

  /* Initialize all configured peripherals */
  MX_GPIO_Init();
  MX_IWDG_Init();
  MX_SPI1_Init();
  /* USER CODE BEGIN 2 */

	//Включаем SPI
	LL_SPI_Enable(SPI1);
	
	//Включаем внешнее прерывание
	LL_EXTI_EnableIT_0_31(LL_EXTI_LINE_2);
	LL_EXTI_EnableFallingTrig_0_31(LL_EXTI_LINE_2);

	nrf24_init();						//инициализируем радиомодуль
	blink_led(5);						//моргаем светодиодом при включении
	
  /* USER CODE END 2 */

  /* Infinite loop */
  /* USER CODE BEGIN WHILE */
  while (1)
  {
		nrf24l01_receive();	//обрабатываем прием радиомодуля
    /* USER CODE END WHILE */

    /* USER CODE BEGIN 3 */
		LL_IWDG_ReloadCounter(IWDG);//сбрасываем сторожевой таймер
		
  }
  /* USER CODE END 3 */
}

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


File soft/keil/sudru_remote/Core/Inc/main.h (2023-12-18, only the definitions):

#define LED_Pin LL_GPIO_PIN_1
#define LED_GPIO_Port GPIOA
#define IRQ_Pin LL_GPIO_PIN_2
#define IRQ_GPIO_Port GPIOA
#define IRQ_EXTI_IRQn EXTI2_3_IRQn
#define CE_Pin LL_GPIO_PIN_3
#define CE_GPIO_Port GPIOA
#define CSN_Pin LL_GPIO_PIN_4
#define CSN_GPIO_Port GPIOA
#define NVIC_PRIORITYGROUP_0         ((uint32_t)0x00000007) /*!< 0 bit  for pre-emption priority,
#define NVIC_PRIORITYGROUP_1         ((uint32_t)0x00000006) /*!< 1 bit  for pre-emption priority,
#define NVIC_PRIORITYGROUP_2         ((uint32_t)0x00000005) /*!< 2 bits for pre-emption priority,
#define NVIC_PRIORITYGROUP_3         ((uint32_t)0x00000004) /*!< 3 bits for pre-emption priority,
#define NVIC_PRIORITYGROUP_4         ((uint32_t)0x00000003) /*!< 4 bits for pre-emption priority,
#define STM32_LL					//stm32, библиотека LL
#define OUR_ADDR 		0xA2	//адрес данного устройства
#define SID_ADDR		0xA1	//адрес пульта управления
#define ON_OFF 			0xC0	//включение/выключение
#define MODE_UP 		0xC3	//смена режима
